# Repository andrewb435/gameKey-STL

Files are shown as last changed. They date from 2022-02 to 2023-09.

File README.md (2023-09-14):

# gameKey #
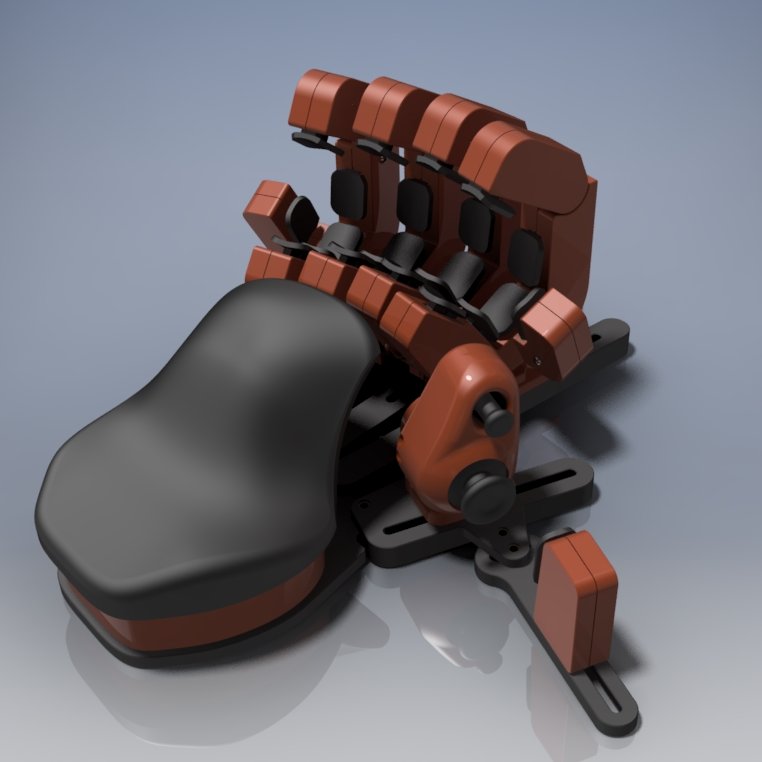
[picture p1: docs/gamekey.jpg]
gameKey STLs


This is an attempt at an easy to print and easy to build adjustable ergonomic game controller. It is based around two custom PCBs, hosting a SparkFun Pro Micro as the main controller (hooked to up to 30 buttons), and a daughterboard containing a joystick and navigation switch for additional controls, including analog.

It uses a combination of M2 and M3 heat-set inserts and as narrow a variety of attachment hardware as reasonably possible. The primary goal is simplicity without sacrificing adjustability or quality.

The entire assembly can be mirrored at the part level to create a version intended to be used with your right hand instead of your left - with the exception of the thumb back/body parts. The control PCB will fit in either direction.

## Printing Notes: ##
The middle and ring finger assemblies are identical. Index is the same, but with a special MainA part to allow the addon to attach. Pinky is a 100% mirror of the Index, with every involved printed part being mirrored.

All printed parts are unique with the exception of:

- 3x Finger_Main-Mount for Index/Middle/Ring (Pinky has a mirrored version)
- 2x Finger_MainA and Finger_MainB for the Middle and Ring fingers
- 4x short button paddles
- 19x of the long paddles

The palm rest may need support in the center depending on your printers bridging capability. The thumb cluster front and back need supports.

## Assembly notes ##
Heatset inserts should also be in the A side of all parts. All shell assembly inserts/bolts are M2, and all adjustment inserts/bolts are M3.

Insert sizes:
* M3 x D4.2 x L3
* M2 x D3 x L2.5

All buttons use 10mm snippets of 1.75mm filament as an axel/pivot.

### Fingers: ###
The switches nestle into the pockets in the A sides of all printed parts and are wired in place. All switches share a common wire that goes to the Column pad on the main control board, with the exception of the side button, which get dedicated lines to their specific row/column pad. Side button assemblies are bolted to the side of the Index/Pinky A-sides before the main buttons go in, as the bolt is under the button at the bottom of the main clusters.

### Thumb Cluster:: ###
The cap for the joystick needs to be inserted into the housing before the circuit board with the Alps stick, as it needs a bit of finagling around the lower edge insert.

### Palmrest: ###
The palmrest itself has 3 M3 inserts in the bottom, with the M3x35 Socket Head Cap Screws going through the lower plate, mid section, and into the palm. The control board has a single M2 insert and screw to fasten and locate it on the base plate.

### Wiring: ###
Most of the fingers and thumb should be straightforward, common pins to the Column pads (C0...C4), but the last column (C5) gets a collection of common pins from several different buttons. This may be changed in a future revision on the PCB, but for now the easiest way is making a small pigtail splitter by soldering the separate wires heading there to a single wire that gets attached to the board.

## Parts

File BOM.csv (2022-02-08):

Item | Qty | Notes | Source
M2 Heat Set Inserts | 31 | M2xD3.0xH2.5 | https://www.aliexpress.com/item/1005002616169567.html?spm=a2g0o.9042311.0.0.27424c4dc1dtaq
M2x8 BHCS | 6 | Thumb cluster and index/pinky side buttons | https://www.mcmaster.com/92095A454/
M2x12 BHCS | 24 | All the fingers and side button cases | https://www.mcmaster.com/92095A455/
M3 Heat Set Inserts | 31 | M3xD4.2xH3.0 | https://www.aliexpress.com/item/1005002615923810.html?spm=a2g0o.detail.1000023.2.2d3d5024rDzQLp
M3x6 BHCS | 28 | Most adjustment screws | https://www.mcmaster.com/92095A179/
M3x10 BHCS | 5 | Knuckle clamps | https://www.mcmaster.com/92095A182/
M3x35 SHCS | 3 | Securing the palmrest to the body | https://www.mcmaster.com/91292A033/
M3 DIN562 Square Nuts | 5 | Knuckle clamps and thumb clamp | https://www.mcmaster.com/97259A101/
Startech 6ft Right Angle Micro B Cable | 1 | USB A to Micro B right angle cable | https://www.startech.com/en-us/cables/uusbhaub6ra
Main Control PCB | 1 | Details in the gameKey-PCB repository
Thumb PCB | 1 | Details in the gameKey-PCB repository
Cat5/6/7/8 Stranded Cable | 14ft | Make sure it’s stranded/patch cable for better flexibility | https://www.monoprice.com/product?p_id=11272
Omron D2FS-F-N-T | 23 | Get a few extra as it’s easy to melt the contacts when soldering | https://www.mouser.com/ProductDetail/Omron-Electronics/D2FS-F-N-T?qs=sEr1OoMjgSAE73IX06aSBA%3D%3D
Thumbstick Cap | 1 | XBOX 360 thumbstick cap | https://www.ebay.com/itm/320898954173?hash=item4ab71173bd:g:u58AAOxyakdRFUeI

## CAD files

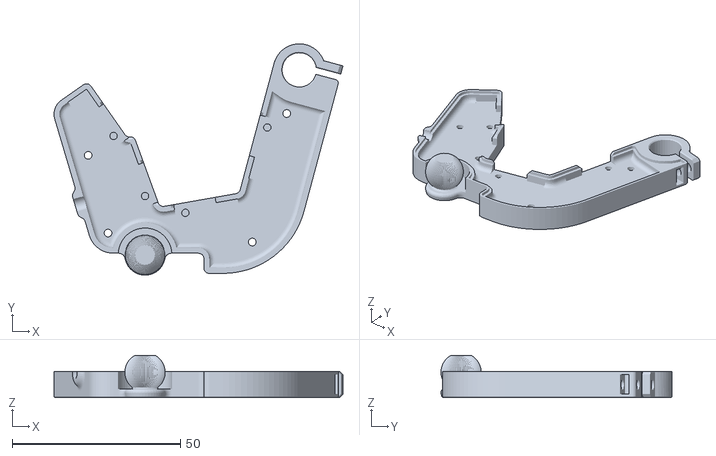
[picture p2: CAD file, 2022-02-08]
Fingers/gameKey_Finger_MainB.stl
85.9 x 68.8 x 12.5

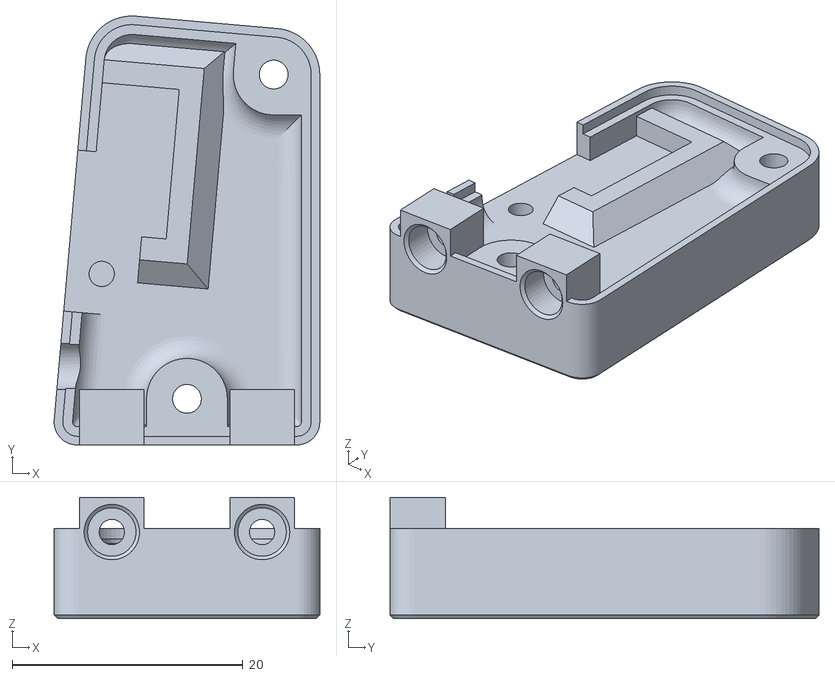
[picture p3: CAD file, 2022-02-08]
Thumb Cluster/gameKey_Thumb_Extension_MainB.stl
23.0 x 37.2 x 10.5

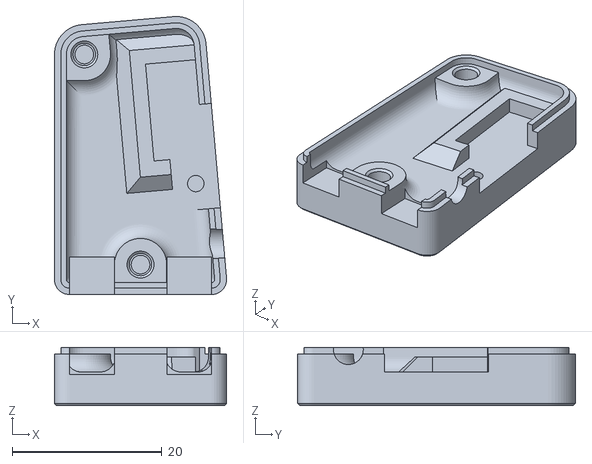
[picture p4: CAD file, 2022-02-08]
Thumb Cluster/gameKey_Thumb_Extension_MainA.stl
23.0 x 37.2 x 7.80

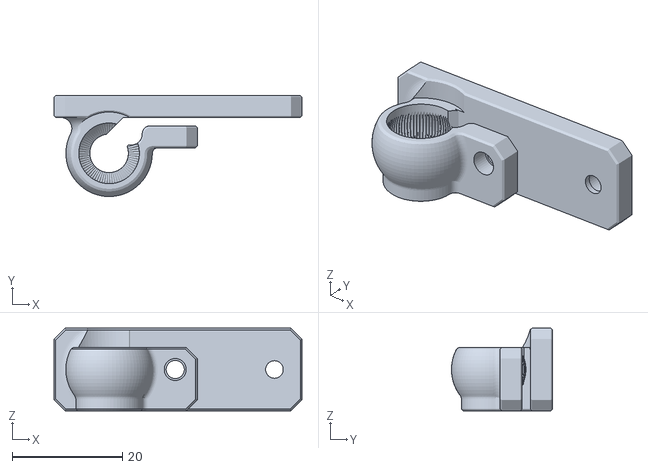
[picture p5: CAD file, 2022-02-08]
Fingers/gameKey_Finger_Main-Mount.stl
45.0 x 18.3 x 15.0

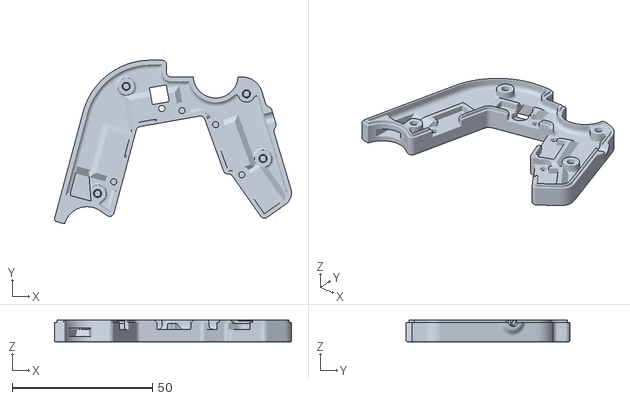
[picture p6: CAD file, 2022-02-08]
Fingers/gameKey_Finger_Pinky-MainA.stl
84.5 x 58.4 x 7.80

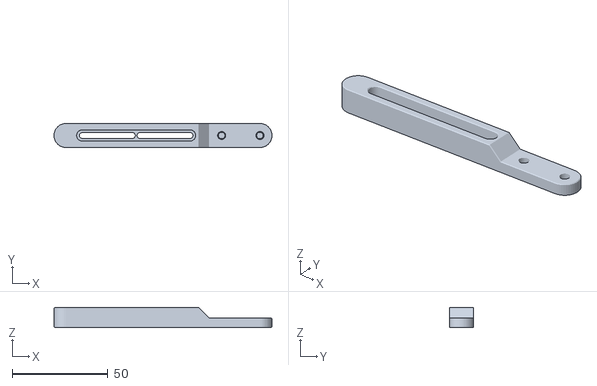
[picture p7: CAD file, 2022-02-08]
Base & Palmrest/gameKey_Finger_SliderMount_Pinky.stl
113.8 x 12.6 x 10.5

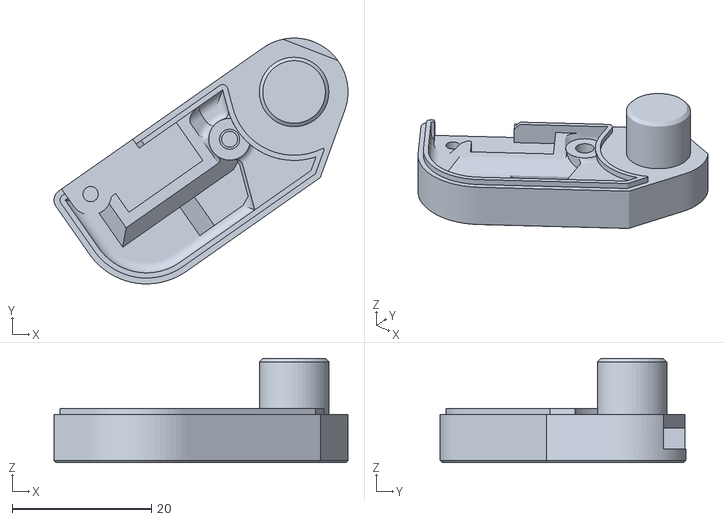
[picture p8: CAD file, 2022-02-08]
Fingers/gameKey_Finger_KnuckleA.stl
42.3 x 35.4 x 15.0

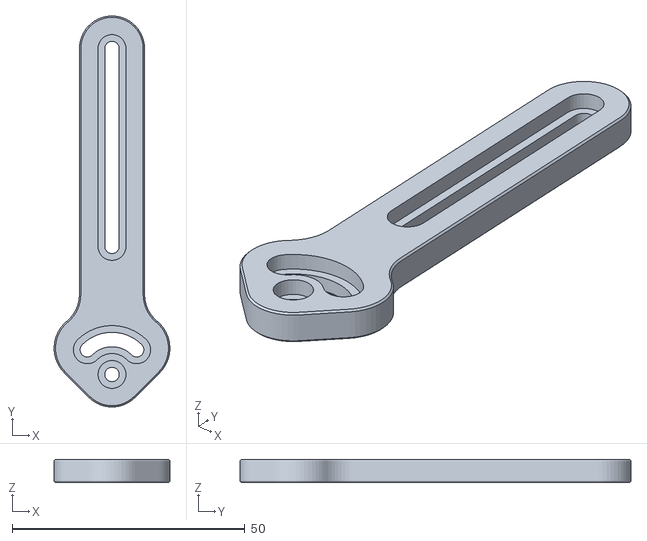
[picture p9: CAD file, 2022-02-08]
Thumb Cluster/gameKey_Thumb_Extension.stl
24.9 x 84.0 x 5.00

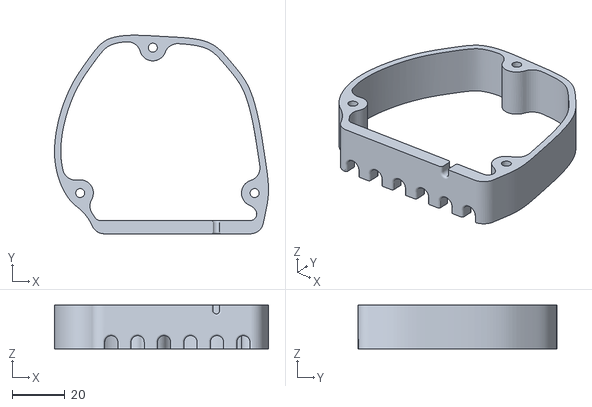
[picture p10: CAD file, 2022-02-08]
Base & Palmrest/gameKey_Palmrest_dMid.stl
81.0 x 75.1 x 16.5

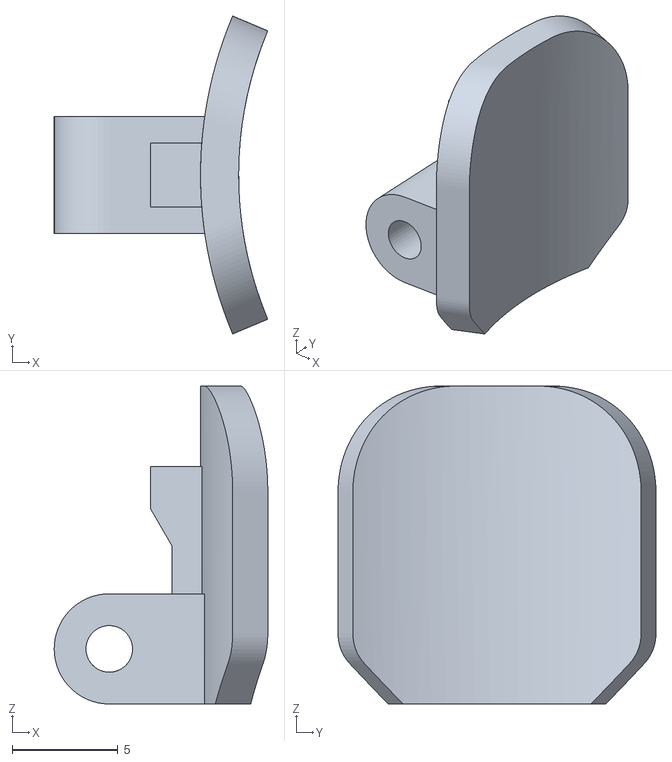
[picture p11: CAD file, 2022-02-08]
Fingers/gameKey_Finger_PaddleSmall.stl
10.1 x 15.0 x 15.0

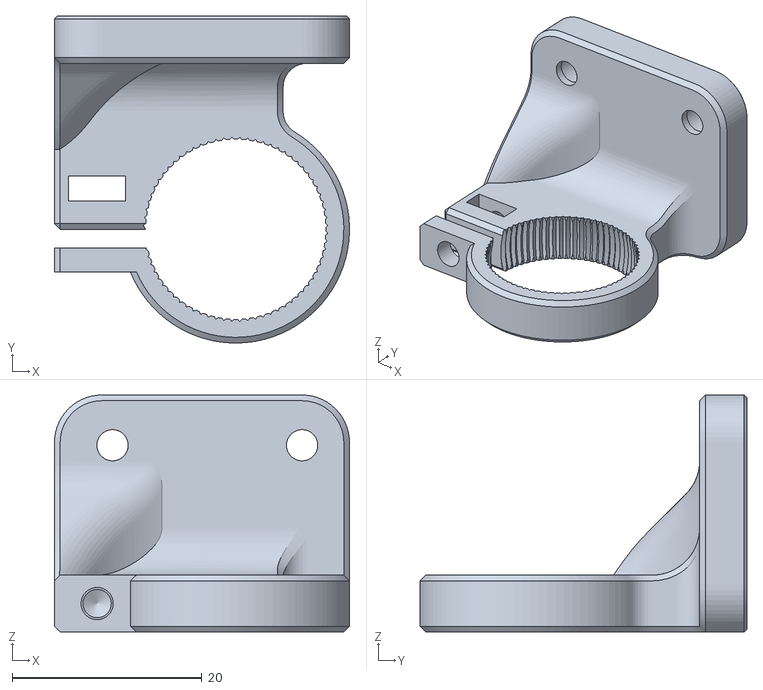
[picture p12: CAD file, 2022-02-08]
Thumb Cluster/gameKey_ThumbCluster_Mount.stl
31.1 x 34.5 x 25.0

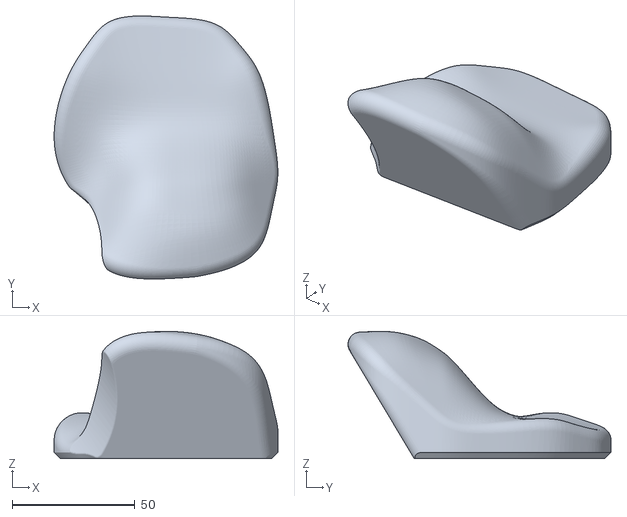
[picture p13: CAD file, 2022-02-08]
Base & Palmrest/gameKey_Palmrest_dPalm.stl
91.0 x 106.9 x 51.7

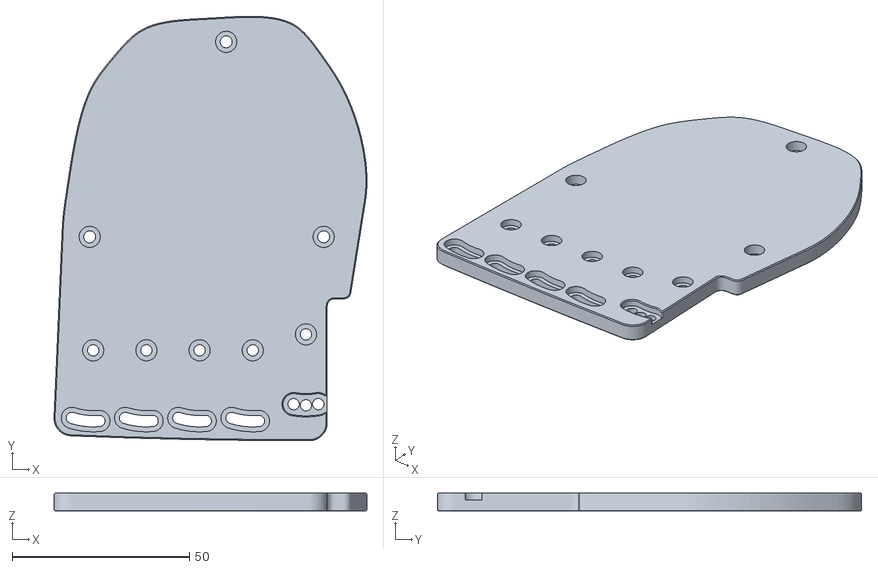
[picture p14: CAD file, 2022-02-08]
Base & Palmrest/gameKey_Palmrest_dBase.stl
88.3 x 119.7 x 5.00

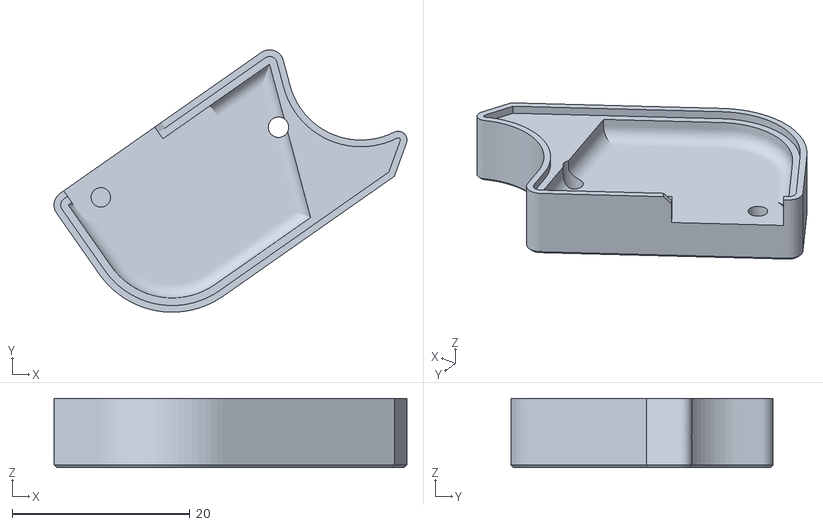
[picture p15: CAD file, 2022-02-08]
Fingers/gameKey_Finger_Pinky-KnuckleB.stl
39.7 x 29.5 x 7.80

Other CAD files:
Fingers/gameKey_Finger_MainA.stl
Fingers/gameKey_Finger_MainA-Index.stl
Fingers/gameKey_Finger_Pinky-MainB.stl
Thumb Cluster/gameKey_Thumb_Rail.stl
Base & Palmrest/gameKey_Finger_SliderMount_Index.stl
Base & Palmrest/gameKey_Finger_SliderMount_Middle.stl
Base & Palmrest/gameKey_Finger_SliderMount_Ring.stl
Fingers/gameKey_Finger_Addon_IndexA.stl
Fingers/gameKey_Finger_Addon_IndexB.stl
Fingers/gameKey_Finger_Addon_PinkyA.stl
Fingers/gameKey_Finger_Addon_PinkyB.stl
Fingers/gameKey_Finger_KnuckleB.stl
Fingers/gameKey_Finger_PaddleLarge.stl
Fingers/gameKey_Finger_Pinky-KnuckleA.stl
Fingers/gameKey_Finger_Pinky-Mount.stl
Thumb Cluster/gameKey_ThumbCluster_Back.stl
Thumb Cluster/gameKey_ThumbCluster_Body.stl
Thumb Cluster/gameKey_ThumbCluster_JS5208-Stick.stl

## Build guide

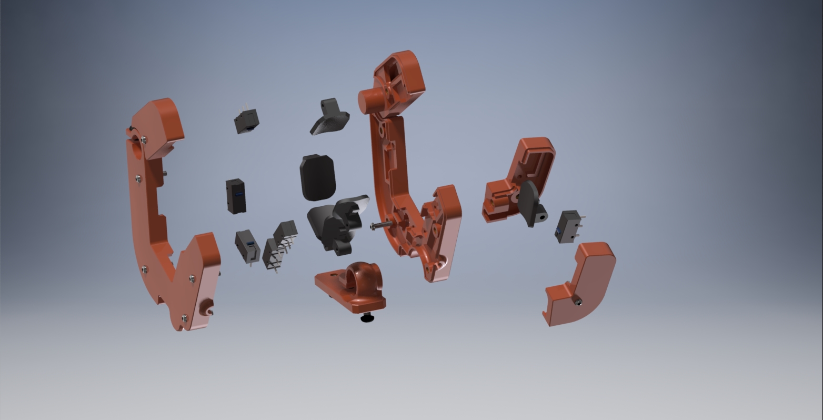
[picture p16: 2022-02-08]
docs/gameKey-Finger-Assembly.jpg
